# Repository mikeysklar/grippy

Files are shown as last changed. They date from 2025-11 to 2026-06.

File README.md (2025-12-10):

# Grippy – Ultracompact One-Handed Keyboard

## Overview

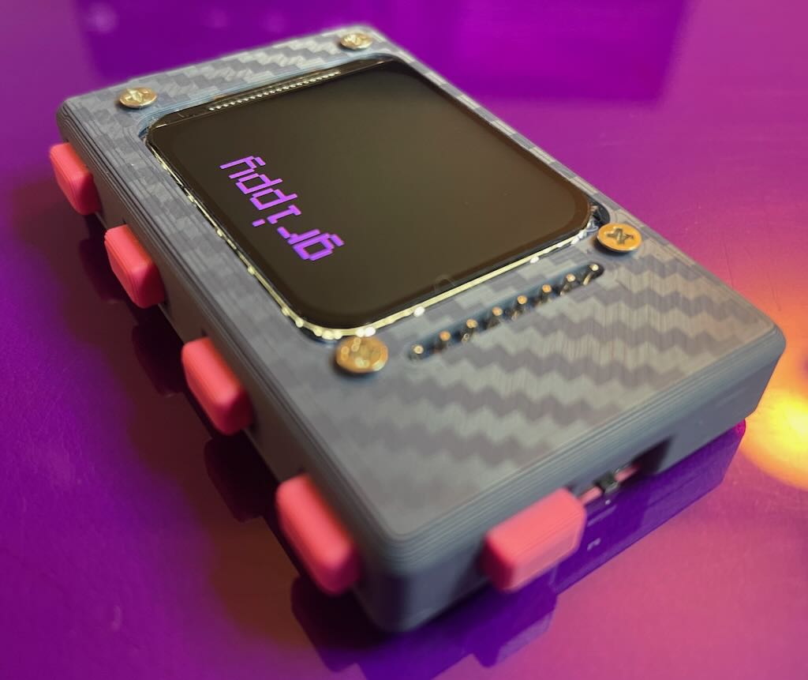
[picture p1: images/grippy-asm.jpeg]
Grippy Assembled


Originally designed as a one-handed chording keyboard for wearables, Grippy has grown through five iterations into a slim, ultralight everyday-carry note-taking device.

Typing around 30 WPM with a single hand—and even inside your pocket—is completely realistic.

Grippy also doubles as a USB or BLE keyboard for phones, tablets, and computers.

---

## Features

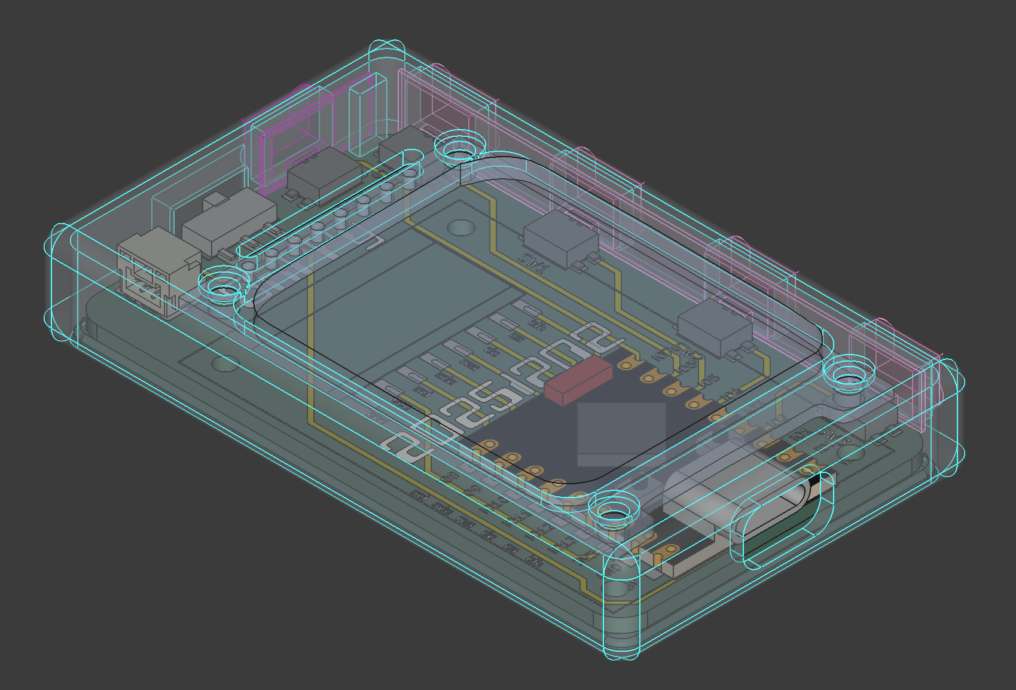
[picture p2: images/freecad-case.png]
FreeCAD


- **Slim & Lightweight**
  - About the thickness of a AAA battery  
  - ~7× lighter than an iPhone  

- **One-Handed SAIE Chording**
  - Full text entry: letters, numbers, symbols  
  - Three layers, zero finger travel  

- **EDC Note-Taking**
  - Write and review notes directly on the device  
  - Works even while pocketed  

- **USB Keyboard Mode**
  - USB HID for quick input or macros  

- **BLE Keyboard Mode**
  - Wireless typing to phones and computers  

- **USB Storage Mode**
  - Mounts as a flash drive to edit notes  

- **Open & Hackable**
  - KiCad, STEP, FreeCAD, and 3MF files  
  - CircuitPython 10.x firmware + chording config

---

## Specs

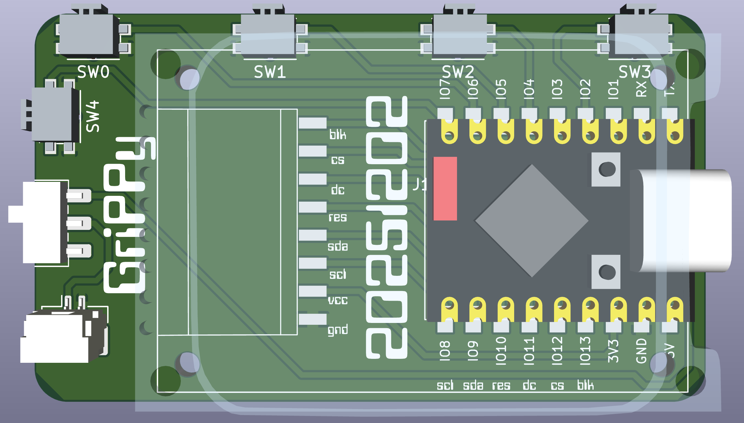
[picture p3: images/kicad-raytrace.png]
3D Board


| Item | Value |
| --- | --- |
| Dimensions  | 61 x 35 x 11 mm |
| Weight | 29 grams |
| Firmware | CircuitPython 10.x |
| Controller  | ESP32-S3 |
| Construction| SMD components on PCB  |

---

## PCB

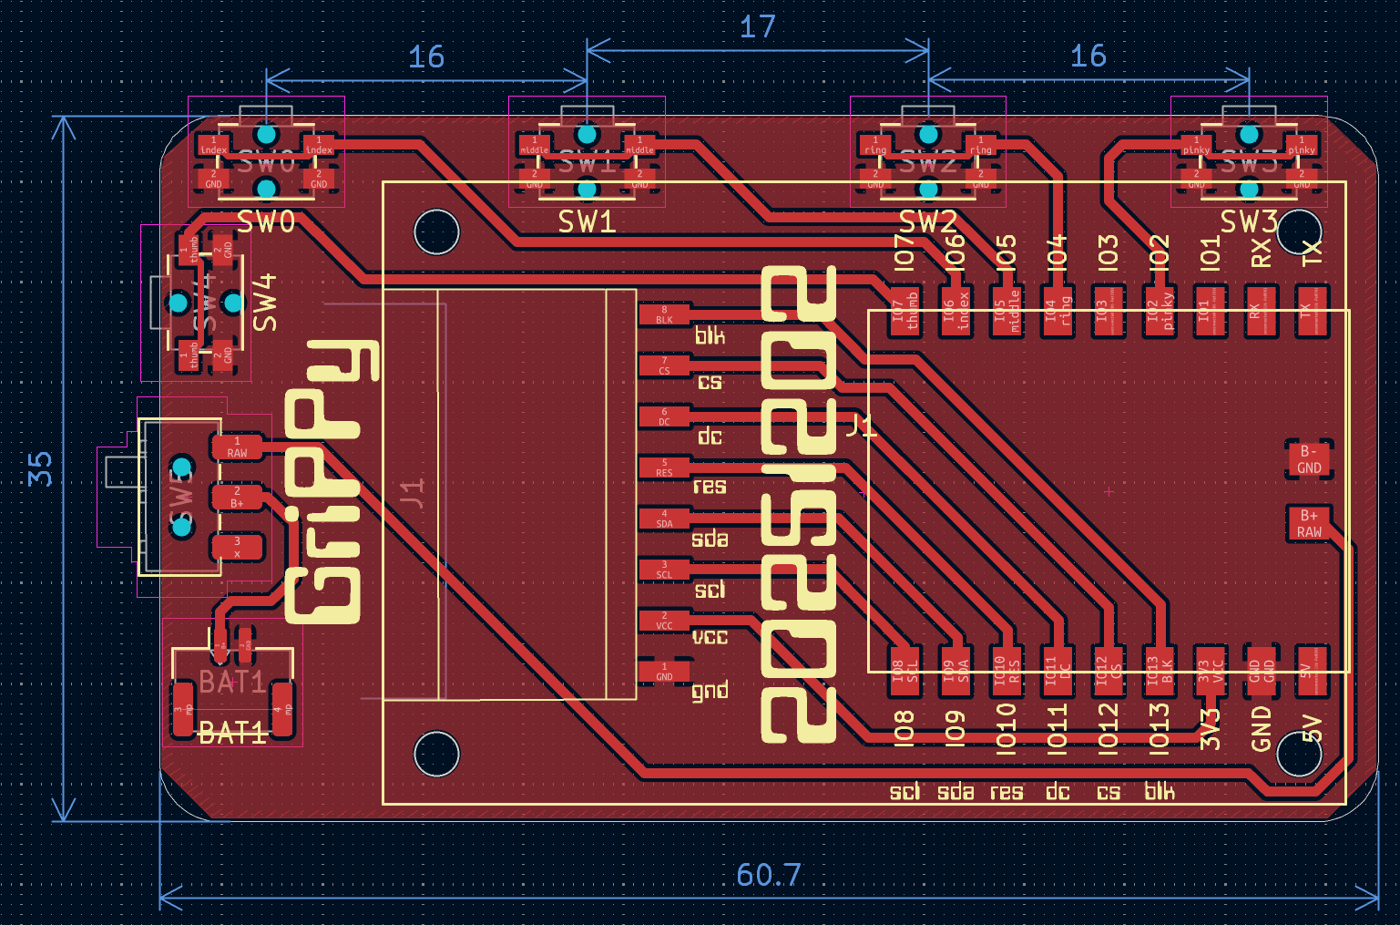
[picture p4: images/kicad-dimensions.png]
PCB Dimensions


- KiCAD 9.x
- single sided PCB
- SMT design

---

## Stencil

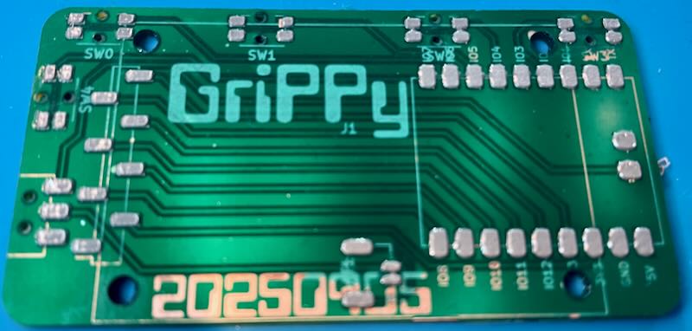
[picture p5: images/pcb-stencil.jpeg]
PCB Stencil


- low temp 140C solderpaste
- laser cut metal business card

---

## Schematic

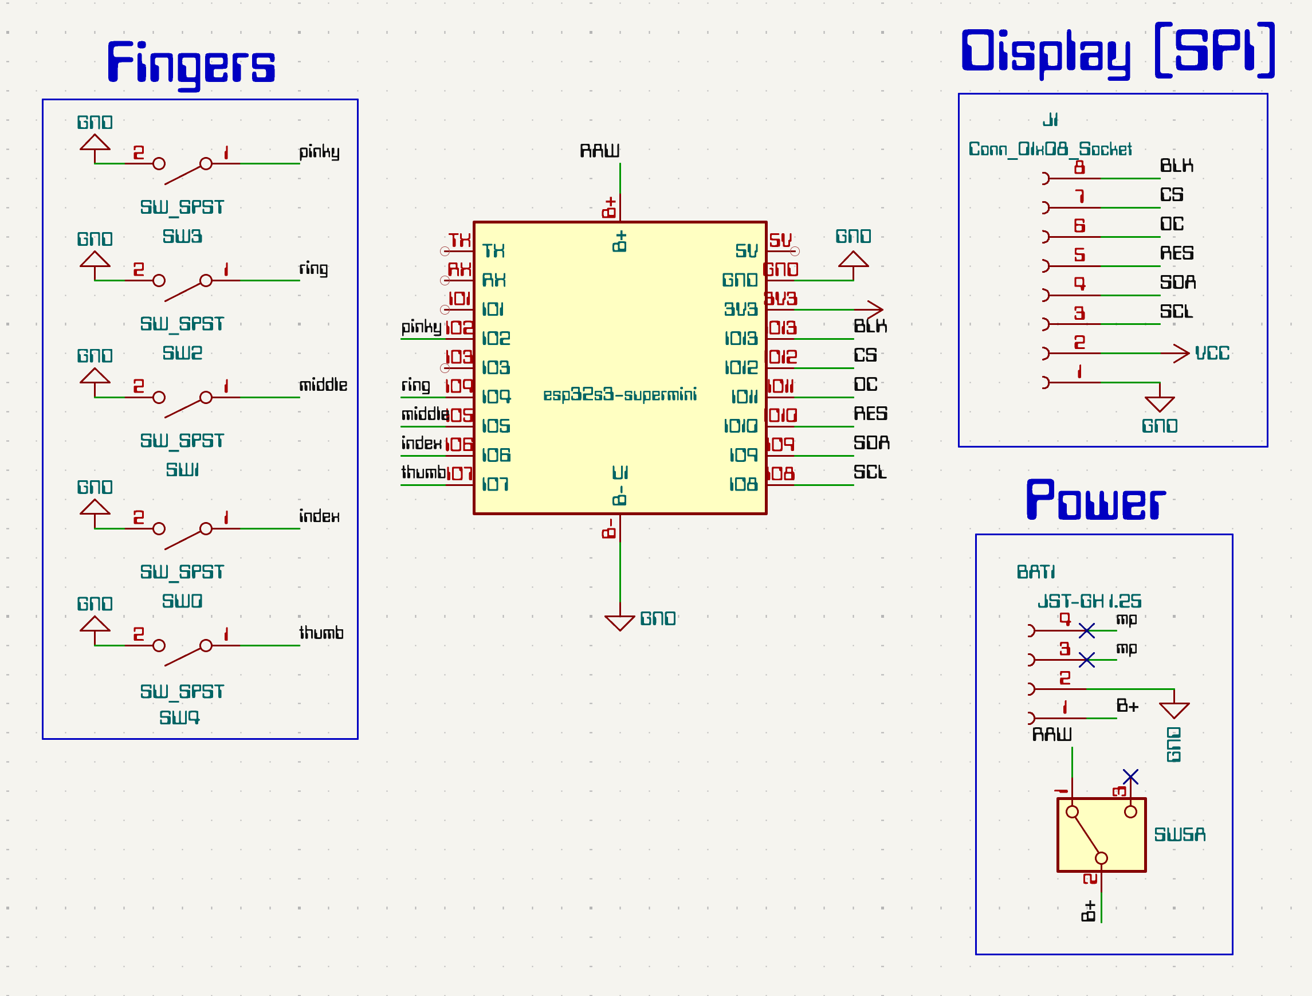
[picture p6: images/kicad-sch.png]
PCB schematic


---

## CircuitPython Setup

- <a href="https://circuitpython.org/board/espressif_esp32s3_devkitc_1_n8/">Bootloader 0.35.0 or later</a>
- <a href="https://circuitpython.org/board/espressif_esp32s3_devkitc_1_n8/">CircuitPython 10.0.3 or later</a>

install library dependencies:

```
circup install adafruit_st7789 adafruit_display_text adafruit_hid
```

copy code:

```
cp src/* CIRCUITPY/
```

---

## BOM

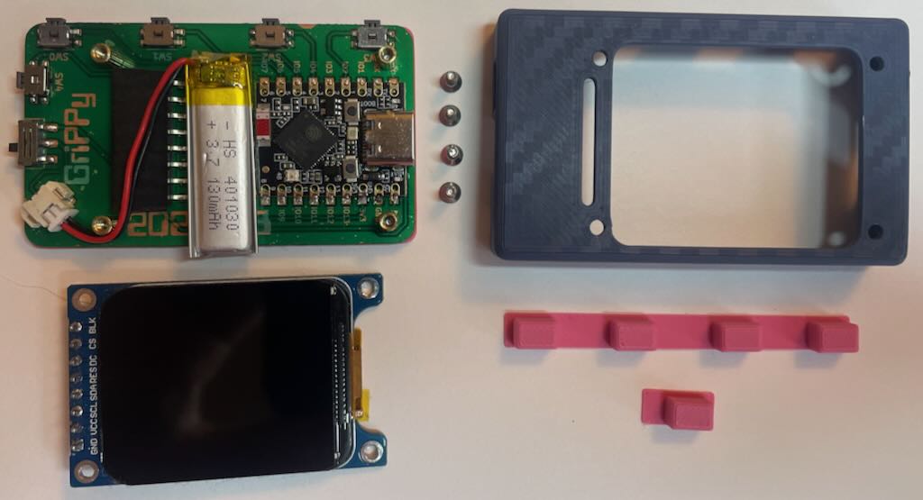
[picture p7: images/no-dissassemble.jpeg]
Inside


| Part | Desc. | Qty |
| --- | --- | --- |
| <a href="https://amzn.to/4idmH0o">ESP32-S3 SuperMini</a> | dual-core 240MHz / 512KB SRAM / 4MB Flash | 1 |
| <a href="https://amzn.to/484M9jT">1.69” TFT Display</a> | ST7789 SPI | 1 |
| <a href="https://www.digikey.com/en/products/detail/panasonic-electronic-components/EVQ-PUL02K/286340">Panasonic Tactile Switch</a> | EVQ-PUL02K SPST-NO Side Actuated | 1 |
| <a href=https://amzn.to/48axBAR>Standoff</a> | M2 × 5 mm | 4 |
| <a href=https://amzn.to/44vQJXr>Screws</a>| M2 × 5 mm | 8 |
| <a href=https://www.aliexpress.us/item/3256804992051151.html>Female SMD Header</a> | 8-pin | 1 |
| <a href=https://www.aliexpress.us/item/3256807383526945.html>Rt Ang Male Header | 8-pin | 1 |
| <a href=https://www.ebay.com/itm/357161444108>Small LiPo Battery | 130 mAh (JST-1.25) | 1 |
| <a href="https://www.aliexpress.us/item/3256805695475806.html">Slide Switch</a>| MSTK-12c03 | 1 |

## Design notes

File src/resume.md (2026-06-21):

# grippy — session resume

Handoff notes to continue this work from another machine.

## Device
- **Board:** ESP32-S3-DevKitC-1-**N8** (8 MB flash, **no PSRAM**, 512 KB SRAM).
- **CircuitPython:** 10.2.0.
- **Display:** 1.69" ST7789 IPS 240×280 (driven 280×240 rot 270) over SPI; **backlight on IO13** (on/off only — PWM has no effect on this panel).
- **Switches:** `SW_PINS = (IO6, IO5, IO4, IO2, IO7)` → chord indices 0–4; **index 4 = thumb** (taps select layers 1–7).
- **Battery:** 130 mAh LiPo. Key constraint — it **cannot source WiFi's sustained ~200–340 mA association burst** → brownout reboot loop. This drove the whole design.

## Git state
- Branch: **`backlight-off`** (off `main`; `main` untouched).
- Committed: `a8b5f0b` "working backlight off" (the original `(3,4)` backlight toggle).
- **Uncommitted/working changes since then** (boot-dark, wake-on-keypress, and now BLE) — see "What changed this session."
- `settings.toml` is **device-local, not in the repo** (never committed — safe for creds).
- ⚠️ If picking up on a different machine, **push from the original machine and pull here**, or these working-tree changes won't be present.

## Power profile (measured, @ ~5.16 V)
| State | WiFi | Backlight | Draw |
|---|---|---|---|
| idle, screen on | idle | on | 150 mA |
| idle, screen off | idle | off | 70 mA |
| screen on, no wifi | off | on | 140 mA |
| both off | off | off | ~60 mA |
| active web access, screen off | TX | off | 130–170 mA |

Decomposition: **base ~60 mA, backlight ~80 mA, WiFi idle ~10 mA, WiFi TX spikes ~200 mA+** (the brownout cause).

## Design decisions (settled)
1. **WiFi is dead on battery.** Any `CIRCUITPY_WIFI_SSID` in `settings.toml` → boot brownout loop (display blinks). Confirmed empirically. Do **not** put WiFi creds in settings.toml.
2. **Backlight boots dark; any key wakes it.** Saves ~80 mA. Reuses the sleep/wake logic.
3. **Never radio + display both on** (battery budget). `(3,4)` = Remote (display off), wake = Local (display on).
4. **Pivoted to BLE** for wireless `notes.txt` editing — low duty cycle, no sustained spike, and `supervisor.runtime.ble_workflow` is a **runtime toggle** (no reload, no settings.toml hacks).

## What changed this session (in `src/code.py`)
- **Boot dark:** both backlight init lines set `bl.value = False` (was a bug — a second line at the old ~line 72 was relighting it).
- **Sleep/wake:** `(3,4)` on layer 3 = sleep (backlight off); **any key on any layer wakes** (rising-edge gated so the `(3,4)` release flicker doesn't re-wake; wake press is consumed). Lives in `check_chords()` as an early `if not bl.value:` block.
- **BLE (new):** at boot, WiFi radio off + `supervisor.runtime.ble_workflow = False` (low power). `(3,4)` → backlight off + `ble_workflow = True`. Wake → backlight on + `ble_workflow = False`.
- Removed all the dead WiFi-connect code (`os`/`wifi` top imports, `ON_BATTERY`, runtime connect).

## settings.toml (device-local) — set this on the board
```toml
CIRCUITPY_BLE_NAME = "grippy"
# NO CIRCUITPY_WIFI_* keys (they brown out the battery at boot)
```

## NEXT STEP — test BLE (do this first)
1. Deploy `src/code.py` to the board (USB drive `cp` when CIRCUITPY mounts host-writable, or Web Workflow — but WW needs WiFi which we removed, so use the **USB drive**). Set `CIRCUITPY_BLE_NAME = "grippy"` in `settings.toml`.
2. On the device: tap thumb ×3 → layer 3, press **thumb+pinky `(3,4)`** → screen goes dark, BLE workflow turns on (serial prints `Remote: backlight OFF, BLE workflow ON (grippy)`).
3. **From a Mac (guaranteed path):** open **Chrome** → `https://code.circuitpython.org` → "Connect via BLE" → pick `grippy` → open/edit/save `notes.txt`.
4. **From iPhone/iPad (untested):** Safari has no Web Bluetooth. Try the **Bluefy** app pointed at `code.circuitpython.org`. If it fails, fall back to a custom Nordic-UART service + Bluefruit Connect (see research below).
5. Test **on battery** to confirm BLE doesn't brown out the 130 mAh cell. (Editing `notes.txt` over BLE only works when CircuitPython owns the FS, i.e. on battery / no USB host; read-only when plugged into USB.)

## Known gotchas / risks
- **No bulk cap (no space).** BLE peaks are still brief ~170 mA — *probably* fine (sub-ms blips vs WiFi's sustained burst) but unverified on this cell. Main thing to confirm in testing.
- **RAM:** no PSRAM. Watch `gc.mem_free()` with BLE + displayio + HID; most likely failure mode.
- **BLE bonding bug** (adafruit/circuitpython #9708) on ESP32-S3 — repeated pair/bond cycles can hard-fault to safe mode; avoid bonding / `_bleio.adapter.erase_bonding()` if it acts up. May still affect 10.2.0.
- **Random EDIT/NOTES storage mode at boot** (no boot.py → `usb_connected` unreliable early). Makes USB deploys flaky — retry resets until CIRCUITPY mounts host-writable, or add a deterministic `boot.py` (wait-for-enumeration → remount). Not yet done.
- Backlight boot **flash**: IO13 floats high (backlight on) from power-on until `code.py` drives it low — unavoidable in software (would need an IO13 pulldown resistor).

## Open / possible follow-ups
- Decide iOS path (Bluefy vs custom NUS service) after testing.
- Optional deterministic `boot.py` to stop the EDIT/NOTES flapping.
- The bigger **Settings menu** idea (layer renumber inserting a Menu at layer 3, combined items) was deferred in favor of this power/BLE work.
- Commit the BLE work and merge `backlight-off` → `main` once BLE is verified.

## Tooling notes
- Board reachable over USB serial via the `circuitpython-repl` MCP (`/dev/cu.usbmodem0FE9E9A75CC81`). The MCP REPL **resets its namespace between calls** — put multi-step snippets in one call.
- Web Workflow creds were `circuitpython.local` / device host `cpy-3_devkitc_1_n8-f09e9e7ac58c.local`, API password `funafuti` — but WiFi is now removed, so Web Workflow is gone; deploy via USB drive.

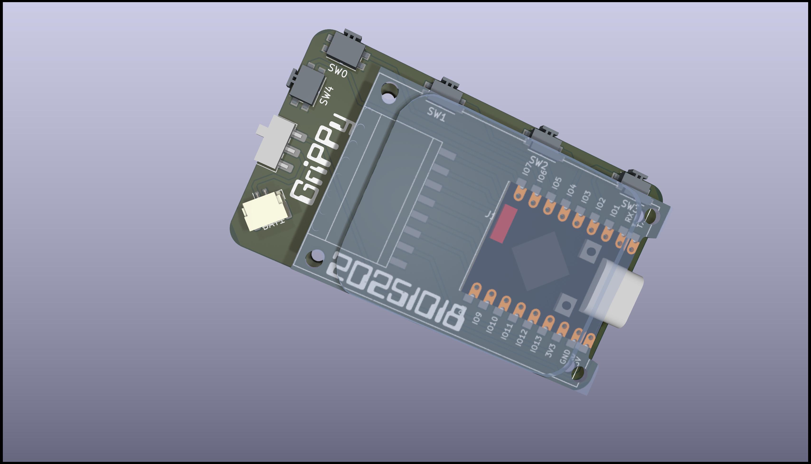
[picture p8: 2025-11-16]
images/kicad-raytrace.jpg

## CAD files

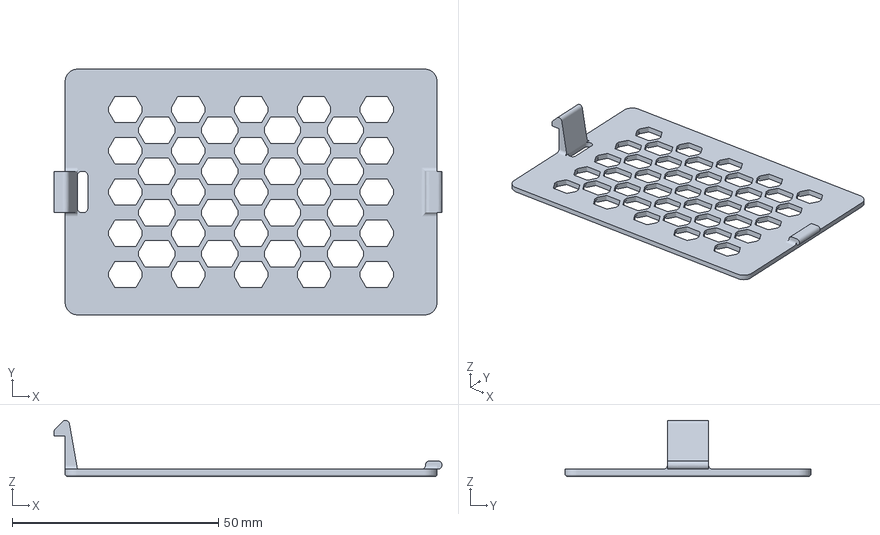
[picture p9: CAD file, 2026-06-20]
cad/grippy-cap.3mf
94.1 x 59.6 x 13.7 mm

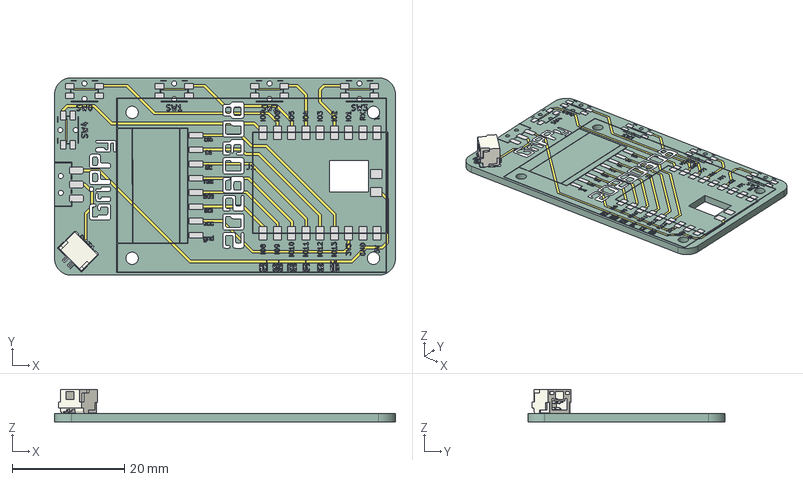
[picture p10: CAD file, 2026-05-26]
grippy/grippy.step
60.8 x 35.2 x 5.92 mm
JST_GH_SM02B-GHS-TB_1x02-1MP_P1.25mm_Horizontal
grippy_copper
grippy_pad
grippy_silkscreen
grippy_PCB

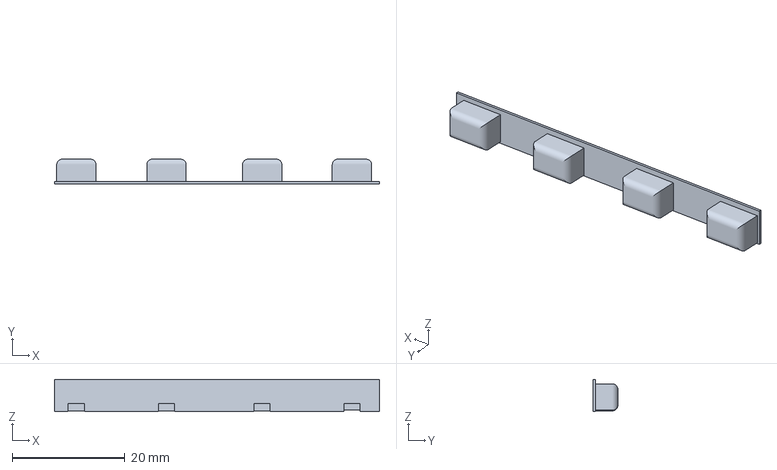
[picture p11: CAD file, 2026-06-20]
cad/grippy-button_fingers.3mf
57.8 x 4.40 x 5.75 mm

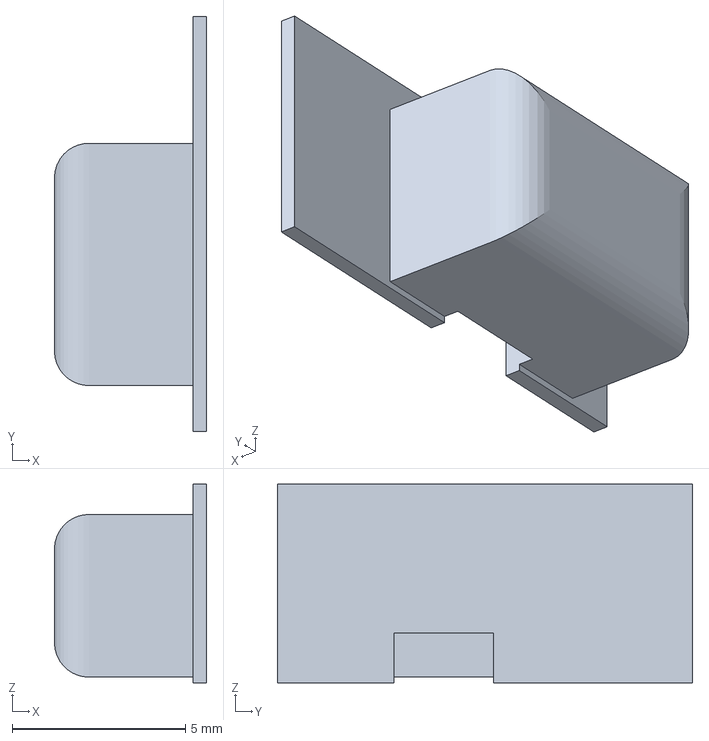
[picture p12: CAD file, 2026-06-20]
cad/grippy-button_thumb.3mf
4.40 x 12.0 x 5.75 mm

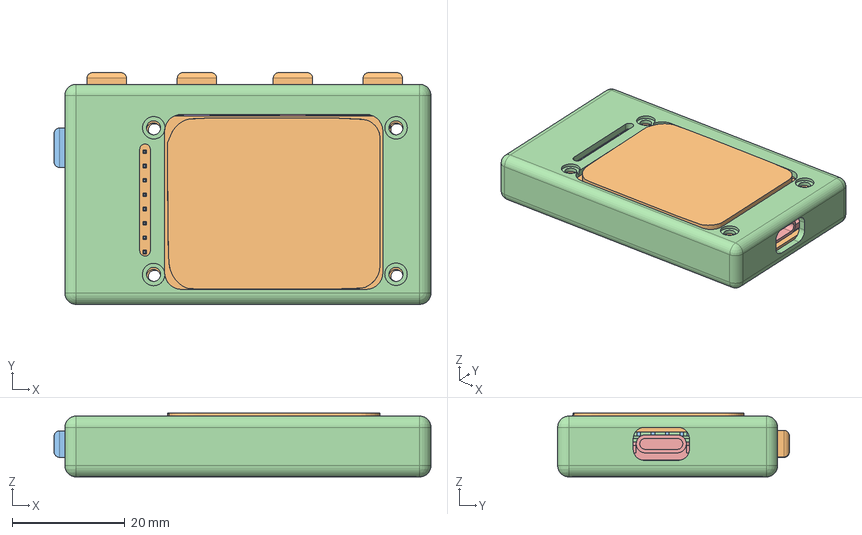
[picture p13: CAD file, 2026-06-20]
cad/grippy.FCStd
66.9 x 41.1 x 11.3 mm
ESP32S3 Super Mini
JST_GH_SM02B-GHS-TB_1x02-1MP_P1.25mm_Horizontal
PinHeader_1x08_P254mm_Horizontal
PinSocket_1x08_P2.54mm_Vertical
grippy_copper
grippy_copper001
grippy_copper002
grippy_copper003
grippy_copper004
grippy_copper005
grippy_copper006
grippy_copper007
grippy_copper008
grippy_copper009
grippy_copper010
grippy_copper011
grippy_copper012
grippy_copper013
grippy_copper014
grippy_pad
grippy_pad001
grippy_pad002
grippy_pad003
grippy_pad004
grippy_pad005
grippy_pad006
grippy_pad007
grippy_pad008
grippy_pad009
grippy_pad010
grippy_pad011
grippy_pad012
grippy_pad013
grippy_pad014
grippy_pad015
grippy_pad016
grippy_pad017
grippy_pad018
grippy_pad019
grippy_pad020
grippy_pad021
grippy_pad022
grippy_pad023
grippy_pad024
grippy_pad025
grippy_pad026
grippy_pad027
grippy_pad028
grippy_pad029
grippy_pad030
grippy_pad031
grippy_pad032
grippy_pad033
grippy_pad034
grippy_pad035
grippy_pad036
grippy_pad037
grippy_pad038
grippy_pad039
grippy_pad040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

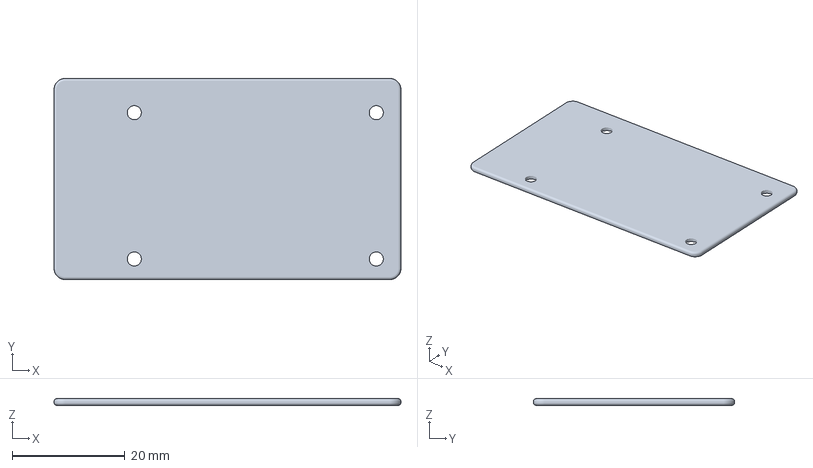
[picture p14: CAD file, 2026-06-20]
cad/grippy-base.3mf
61.7 x 35.8 x 1.20 mm

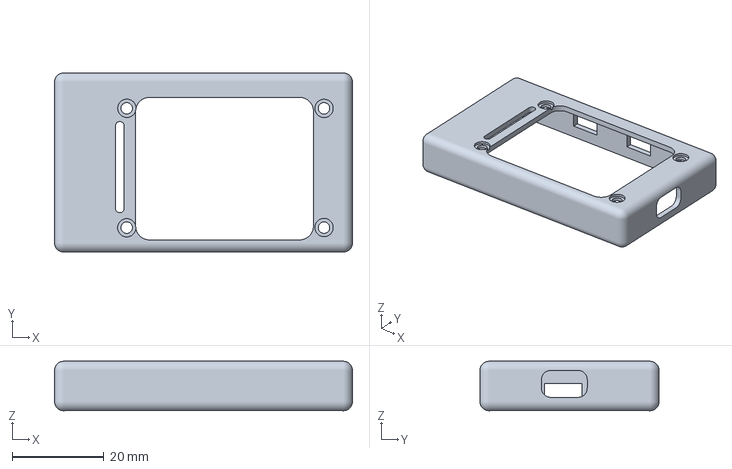
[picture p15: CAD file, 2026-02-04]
cad/grippy-capPocket049.3mf
65.0 x 39.0 x 10.8 mm

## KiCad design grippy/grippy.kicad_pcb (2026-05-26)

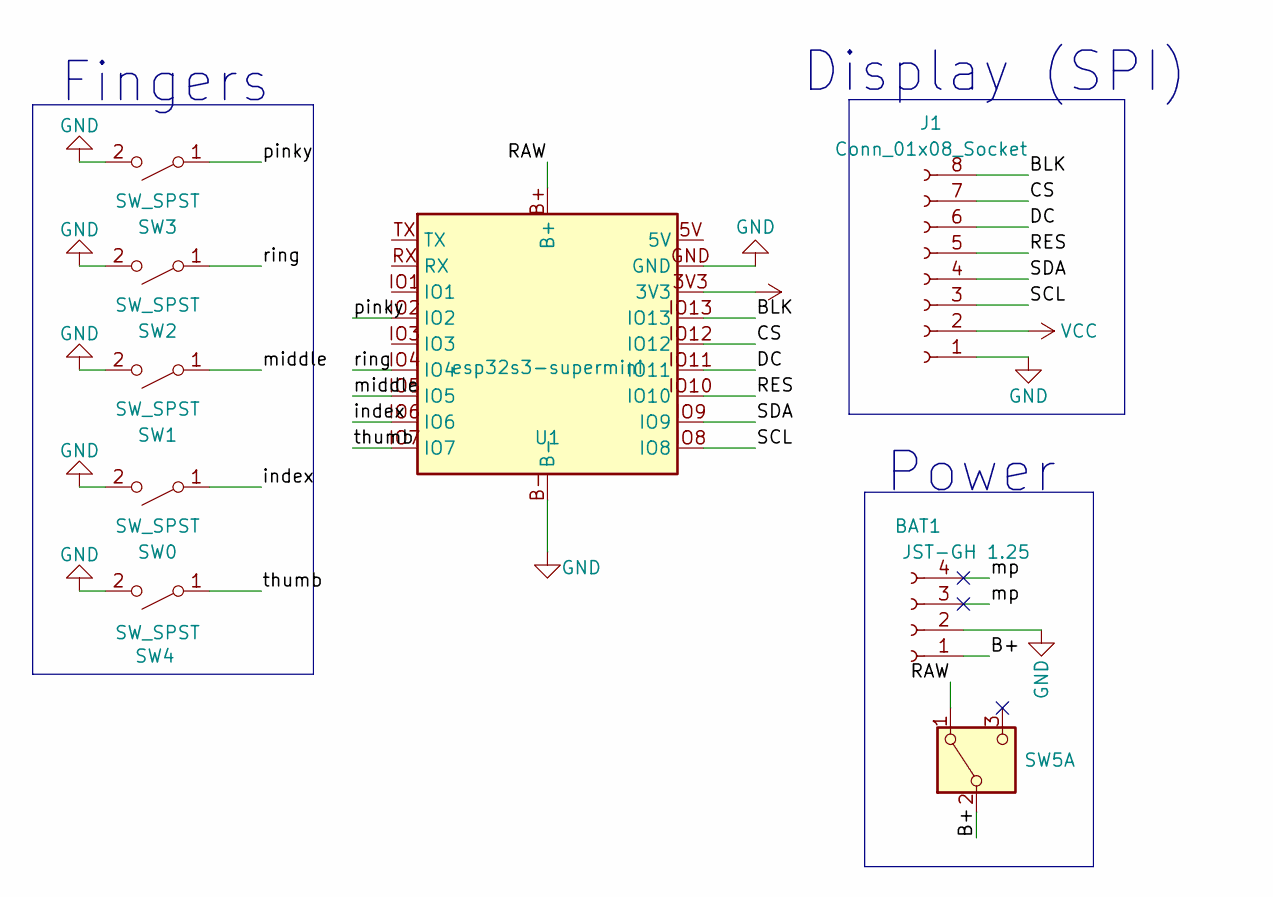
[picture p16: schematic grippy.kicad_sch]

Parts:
BAT1: JST-GH 1.25; JST_GH_SM02B-GHS-TB_1x02-1MP_P1.25mm_Horizontal
J1: Conn_01x08_Socket; tft-169-st7789-rt-ang
SW0, SW1, SW2, SW3, SW4: SW_SPST; Panasonic_EVQPUL_EVQPUC
SW5: SW_DPDT_x2; Untitled
U1: esp32s3-supermini; ESP32-S3-SuperMini_SMT

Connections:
/B+: BAT1.1, SW5.2 (B)
/BLK: J1.8, U1.IO13
/CS: J1.7, U1.IO12
/DC: J1.6, U1.IO11
/RAW: SW5.1 (A), U1.B+
/RES: J1.5, U1.IO10
/SCL: J1.3, U1.IO8
/SDA: J1.4, U1.IO9
/index: SW0.1 (A), U1.IO6
/middle: SW1.1 (A), U1.IO5
/mp: BAT1.3, BAT1.4
/pinky: SW3.1 (A), U1.IO2
/ring: SW2.1 (A), U1.IO4
/thumb: SW4.1 (A), U1.IO7
GND: BAT1.2, J1.1, SW0.2 (B), SW1.2 (B), SW2.2 (B), SW3.2 (B), SW4.2 (B), U1.B-, U1.GND
VCC: J1.2, U1.3V3

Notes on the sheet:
Fingers
Display (SPI)
Power

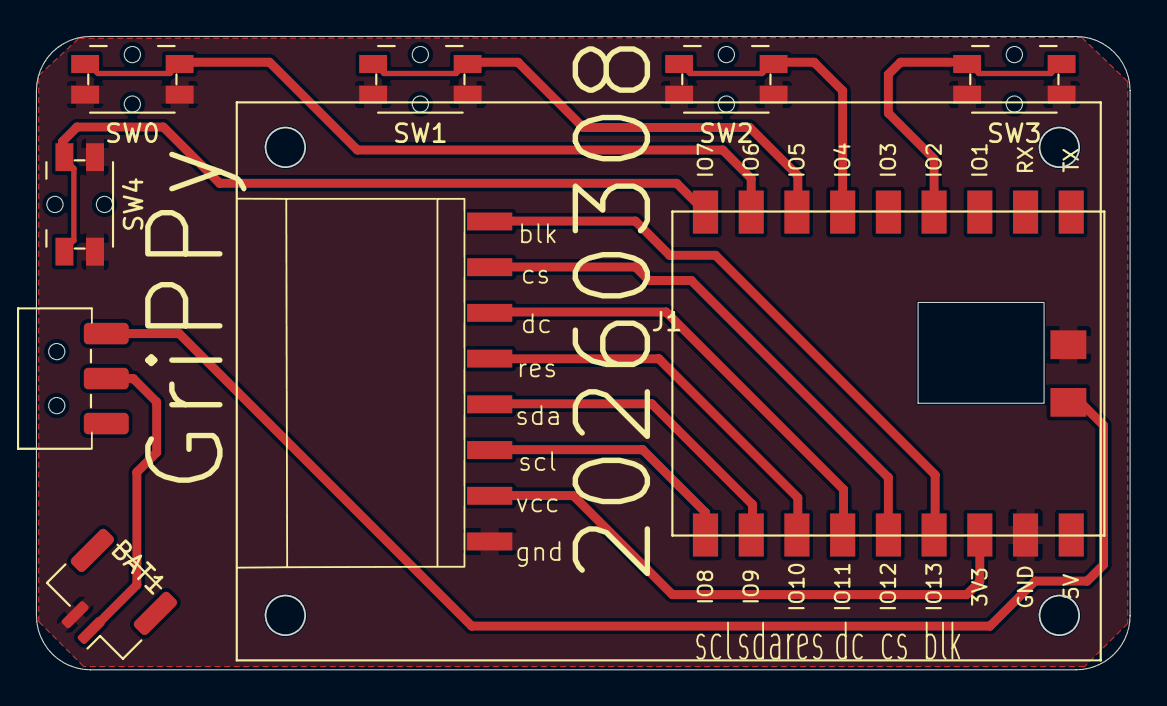
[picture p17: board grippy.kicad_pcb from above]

Board: 2 copper layers, 60.8 x 35.2 mm, 9 parts (0 on the bottom side), 16 nets.

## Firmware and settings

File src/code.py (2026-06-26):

import time
import digitalio
import board
import busio
import displayio
from fourwire import FourWire
from adafruit_st7789 import ST7789
import terminalio
from adafruit_display_text import bitmap_label as label
import chords_config
import webserver
import notes
import game
import ble_hid

time.sleep(0.25)
displayio.release_displays()

# --- WiFi radio off (no networking; saves power) ---
try:
    import wifi
    wifi.radio.enabled = False
except Exception:
    pass

# --- BLE radio: OFF at boot (enabled on demand) ---
# An enabled-but-idle BLE controller draws current on EVERY boot even when BLE
# is never used. So leave the adapter OFF here and let ble_hid.start() power it
# up the first time the BLE menu item is selected (with a settle delay before
# advertising, so we still don't toggle adapter.enabled right next to a
# start_advertising — the thing that used to corrupt the controller).
#
# Still disable CircuitPython's built-in BLE WORKFLOW. It auto-advertises as
# CIRCUITPYxxxx and re-advertises on every disconnect, fighting ble_hid for the
# single radio — that caused the stray "CIRCUITPYac58e" name, macOS staying
# connected after BLE-off (workflow re-advertised → host reconnected), and the
# flaky pairing. boot.py disables it before it ever starts on a hard reset; this
# line covers soft resets (Ctrl-D), where boot.py does not run.
try:
    import supervisor
    supervisor.runtime.ble_workflow = False
except Exception:
    pass
try:
    import _bleio
    if _bleio.adapter.advertising:
        _bleio.adapter.stop_advertising()
    _bleio.adapter.enabled = False
except Exception:
    pass

# --- Backlight ---
bl = digitalio.DigitalInOut(board.IO13)
bl.direction = digitalio.Direction.OUTPUT
bl.value = True

# --- Onboard RGB LED off (case covers it; saves power) ---
# CircuitPython drives the WS2812 on board.NEOPIXEL as a status LED. Drive it to
# black with the built-in neopixel_write (no neopixel lib needed) and release the
# pin. (The separate red power LED is hardwired to 3V3 — not software-controllable.)
try:
    import neopixel_write
    _np = digitalio.DigitalInOut(board.NEOPIXEL)
    _np.direction = digitalio.Direction.OUTPUT
    neopixel_write.neopixel_write(_np, bytearray([0, 0, 0]))
    _np.deinit()
except Exception:
    pass

# --- SPI + 4-wire display bus ---
spi = busio.SPI(clock=board.IO8, MOSI=board.IO9)   # no MISO required
display_bus = FourWire(
    spi,
    command=board.IO11,        # D/C
    chip_select=board.IO12,    # CS
    reset=board.IO10,          # RST
    baudrate=60_000_000
)

# --- ST7789 panel (280x240 variant) ---
display = ST7789(
    display_bus,
    width=280,
    height=240,
    rotation=270,
    rowstart=20,
    colstart=0,
    auto_refresh=False,
)

display_group = displayio.Group(scale=1)
display.root_group = display_group

# --- Black background tile ---
bg_bitmap = displayio.Bitmap(280, 240, 1)
bg_palette = displayio.Palette(1)
bg_palette[0] = 0x000000
bg = displayio.TileGrid(bg_bitmap, pixel_shader=bg_palette)
display_group.append(bg)

try:
    display.refresh(minimum_frames_per_second=0)
except TypeError:
    display.refresh()

bl.value = True  # backlight on

# ─── Text buffer ─────────────────────────────────────────────────────
text_buffer = ""

# ─── Switch inputs ───────────────────────────────────────────────────
SW_PINS = (board.IO6, board.IO5, board.IO4, board.IO2, board.IO7)
pins = []
for gp in SW_PINS:
    p = digitalio.DigitalInOut(gp)
    p.direction = digitalio.Direction.INPUT
    p.pull = digitalio.Pull.UP
    pins.append(p)

# ─── Keyboard output (start OFF) ─────────────────────────────────────
# Two transports, one at a time: USB HID (`usbmode`, local `keyboard`) and
# BLE HID (`blemode`, owned by ble_hid). _kbd() returns whichever is ready to
# send (None if off, or BLE-on-but-not-yet-connected).
usbmode = False
blemode = False
keyboard = None
ble_err  = ""        # last BLE-enable error (shown on screen for debugging)

def enable_hid():
    global usbmode, keyboard
    if blemode:
        disable_ble()            # one transport at a time
    import usb_hid
    from adafruit_hid.keyboard import Keyboard
    keyboard = Keyboard(usb_hid.devices)
    usbmode = True
    print("USB HID enabled")

def disable_hid():
    global usbmode, keyboard
    keyboard = None
    usbmode = False
    print("USB HID disabled")

def enable_ble():
    global blemode, ble_err
    if usbmode:
        disable_hid()            # one transport at a time
    import gc
    gc.collect()
    print("BLE: free heap before start =", gc.mem_free())
    try:
        ble_hid.start("grippy")
        blemode = True
        ble_err = ""
        print("BLE HID enabled (advertising as grippy)")
    except Exception as e:
        blemode = False          # never crash the device on a radio hiccup
        ble_err = repr(e)
        try:
            ble_hid.stop()
        except Exception:
            pass
        print("BLE enable FAILED:", ble_err)

def disable_ble():
    global blemode
    ble_hid.stop()
    blemode = False
    print("BLE HID disabled")

def _kbd():
    """The keyboard ready to send right now, or None."""
    if usbmode:
        return keyboard
    if blemode:
        return ble_hid.kbd()     # None until a host connects
    return None

# ─── Timing constants ────────────────────────────────────────────────
SCAN_LOOP = 0.001
# While the screen is OFF (local sleep or WiFi Sync) there is nothing to type,
# so we don't need the 1 ms chord-scan cadence — spinning that fast keeps the
# ESP32-S3 CPU out of idle and burns ~70 mA extra (measured: screen-off+WiFi
# busy-spin 140 mA vs 70 mA when the CPU is allowed to idle). Poll at 20 Hz
# instead: still wakes on a keypress / serves HTTP within 50 ms, but lets the
# CPU idle so screen-off draw drops back to ~70 mA on the 130 mAh cell.
SLEEP_LOOP = 0.05
STABLE_MS_ALPHA = 0.03
STABLE_MS_OTHER = 0.02
DEBOUNCE_UP      = 0.05
TAP_WINDOW       = 0.5
MIN_TAP_INT      = 0.1
L5_REPEAT_MS     = 0.1
NAV_REPEAT_MS    = 0.2
LAYER_LOCK_COOLDOWN = 0.1
SCROLL_REPEAT_MS  = 0.15
THUMB_HOLD_TO_LOCK = 0.12
LONG_HOLD_MENU    = 0.70   # thumb-only hold ≥ this ⇒ jump to the menu (longer = taps to alpha are safer)
NEXT_OK = 0.0

# ─── State variables ────────────────────────────────────────────────
layer            = 1
thumb_taps       = 0
tap_in_prog      = False
thumb_down_at    = 0.0
long_hold_fired  = False
thumb_gesture    = False   # True only while the thumb is held ALONE from rest;
                           # a lone (4,) reached by releasing a chord's fingers
                           # is NOT a gesture (it's a chord tail) and must reach
                           # the typing/game handler instead of switching layer.
last_tap_time    = 0.0
last_combo       = ()
pending_combo    = None
sent_release     = False
skip_scag        = False
scag_skip_combo  = None
modifier_armed   = False
held_modifier    = None
last_time        = time.monotonic()
held_combo       = ()
last_repeat      = 0.0
accel_active     = False
held_nav_combo   = ()
last_nav         = 0.0
last_pending_combo = None
last_layer_change = 0.0
held_scroll_combo = ()
last_scroll       = 0.0
last_thumb_rise    = 0.0
thumb_locked       = False
viewer_mode  = False
entries      = []
entry_idx    = 0
entry_offset = 0
typing_offset = 0

# ─── Menu / sub-mode state ───────────────────────────────────────────
# A note auto-saves on the long-hold back to the menu (the only way home),
# so layer switches never commit and there's no separate Save item.
_BASE_MENU = ["New Note", "View Note", "WiFi Sync", "Clr Note", "Game Mode", "BLE", "Clr BLE", "HID", "Clr All"]
menu_idx          = 0
menu_top          = 0
confirm_clear_all = False
confirm_clr_ble   = False     # "Clr BLE" two-tap confirm (erases BLE bonds)
clear_mode        = False     # "Clr Note" picker active
clear_idx         = 0
clear_top         = 0
game_mode         = False     # chord-trainer (game.py) active

# ─── Text window geometry for ST7789 ─────────────────────────────────
SCALE   = 4
GLYPH_W = 6 * SCALE          # terminalio glyph is 6x8
GLYPH_H = 8 * SCALE
COLS    = 10                 # ~10 chars/row at scale=4 fits well
ROWS    = 5                  # 5 rows on screen
LEFT, TOP = 20, 0
LINE_SPACING = 11            # extra pixels between rows

line_labels = []
_shown_lines = [""] * ROWS
for r in range(ROWS):
    lbl = label.Label(
        terminalio.FONT,
        text="",
        color=0xFF00FF,
        x=LEFT,
        y=TOP + (r + 1) * GLYPH_H + r * LINE_SPACING,
        scale=SCALE,
    )
    display_group.append(lbl)
    line_labels.append(lbl)

def _set_line(row: int, s: str) -> bool:
    """Update one line if text changed; return True if dirtied."""
    if s != _shown_lines[row]:
        line_labels[row].text = s
        _shown_lines[row] = s
        return True
    return False

def _format_window_lines(s: str):
    win = COLS * ROWS
    s = s + " " * max(0, win - len(s))
    return [s[i:i+COLS] for i in range(0, win, COLS)]

def _wrap_lines(s: str, cols: int = COLS):
    """Word-wrap s into rows of <= cols chars, breaking on spaces so whole
    words drop to the next row instead of splitting (used by View mode).
    Honors explicit newlines; a word longer than cols is hard-split since it
    can never fit. Whitespace runs collapse to a single space."""
    out = []
    for para in s.split("\n"):
        words = para.split()
        if not words:
            out.append("")          # preserve blank lines / paragraph breaks
            continue
        line = ""
        for w in words:
            while len(w) > cols:    # too long to ever fit a row: hard-split
                if line:
                    out.append(line); line = ""
                out.append(w[:cols]); w = w[cols:]
            if not line:
                line = w
            elif len(line) + 1 + len(w) <= cols:
                line += " " + w
            else:
                out.append(line); line = w
        if line:
            out.append(line)
    return out

# ─── Budgeted manual refresh ─────────────────────────────────────────
USE_NS = hasattr(time, "monotonic_ns")
_now = (time.monotonic_ns if USE_NS else lambda: int(time.monotonic()*1_000_000_000))

NEEDS_REFRESH = False
LAST_REFRESH_NS = 0
MIN_REFRESH_INTERVAL_NS = int(1e9 / 55)   # ~55 fps cap (~18ms)

def _maybe_refresh_budgeted():
    global NEEDS_REFRESH, LAST_REFRESH_NS
    if not NEEDS_REFRESH:
        return
    now_ns = _now()
    if (now_ns - LAST_REFRESH_NS) >= MIN_REFRESH_INTERVAL_NS:
        try:
            display.refresh(minimum_frames_per_second=0)
        except TypeError:
            display.refresh()
        LAST_REFRESH_NS = now_ns
        NEEDS_REFRESH = False

# ─── edit view ──────────────────────────────────────────────
def render_typing_window():
    """Render a COLS×ROWS window of text_buffer starting at typing_offset."""
    global typing_offset, NEEDS_REFRESH
    win = COLS * ROWS
    typing_offset = max(0, min(typing_offset, max(0, len(text_buffer) - win)))
    start, end = typing_offset, typing_offset + win
    lines = _format_window_lines(text_buffer[start:end])
    dirty = False
    for r, s in enumerate(lines):
        dirty |= _set_line(r, s)
    if dirty:
        NEEDS_REFRESH = True

# ─── Save-to-file (note storage lives in notes.py) ───────────────────
def save_entry():
    global text_buffer
    if notes.append_entry(text_buffer.rstrip("\n")):
        text_buffer = ""
        render_typing_window()

# ─── viewer mode ───────────────────────────────────────────────
def load_entries():
    global entries, entry_idx, entry_offset
    entries = notes.read_entries()
    entry_idx = 0
    entry_offset = 0

def render_entry_window():
    global NEEDS_REFRESH
    if not entries:
        d = _set_line(0, "(no notes)")
        d |= _set_line(1, "")
        d |= _set_line(2, "")
        d |= _set_line(3, "")
        if d: NEEDS_REFRESH = True
        return
    s = entries[entry_idx]
    wrapped = _wrap_lines(s, COLS)          # break on spaces, no mid-word splits
    max_off = max(0, len(wrapped) - ROWS)
    start = max(0, min(entry_offset, max_off))
    view = wrapped[start:start+ROWS]
    d = False
    for r in range(ROWS):
        d |= _set_line(r, view[r] if r < len(view) else "")
    if d: NEEDS_REFRESH = True

def enter_viewer():
    # NOTE: do NOT clear text_buffer — an in-progress note must survive a peek
    # at the viewer (resume it later via "Add Note").
    global viewer_mode, NEEDS_REFRESH
    d = False
    for r in range(ROWS):
        d |= _set_line(r, "")
    if d: NEEDS_REFRESH = True
    load_entries()
    viewer_mode = True
    render_entry_window()

def _update_last_char_only():
    global NEEDS_REFRESH
    win = COLS * ROWS
    start = typing_offset
    caret = len(text_buffer) - 1
    if caret < start or caret >= start + win:
        return
    rel = caret - start
    row = rel // COLS
    row_start = start + row * COLS
    row_text = text_buffer[row_start:row_start+COLS]
    row_text = row_text + " " * max(0, COLS - len(row_text))
    if _set_line(row, row_text):
        NEEDS_REFRESH = True

# ─── Printable-char map for the local note buffer ────────────────────
# HID keycode → character to echo into text_buffer. Letters/digits are
# computed; punctuation & whitespace come from this table. Non-printable
# keys (Esc, arrows, nav, Delete) map to None → sent over HID but not echoed.
_KC_CHAR = {
    39: "0", 40: "\n", 43: " ", 44: " ", 45: "-", 46: "=",
    47: "[", 48: "]", 49: "\\", 51: ";", 52: "'", 53: "`",
    54: ",", 55: ".", 56: "/",
}

def _kc_to_char(kc):
    if 4 <= kc <= 29:
        return chr(kc - 4 + ord('a'))
    if 30 <= kc <= 38:
        return chr(kc - 30 + ord('1'))
    return _KC_CHAR.get(kc)

# ─── Menu (layer 1) ──────────────────────────────────────────────────
def menu_items():
    return _BASE_MENU

def render_menu():
    """Draw the layer-1 menu as a scrolling ROWS-high window with a > cursor."""
    global NEEDS_REFRESH, menu_top, menu_idx
    items = menu_items()
    n = len(items)
    if menu_idx >= n:
        menu_idx = n - 1
    if menu_idx < 0:
        menu_idx = 0
    if menu_idx < menu_top:
        menu_top = menu_idx
    elif menu_idx >= menu_top + ROWS:
        menu_top = menu_idx - ROWS + 1
    dirty = False
    for r in range(ROWS):
        i = menu_top + r
        if i < n:
            name = items[i]
            if name == "HID":
                name = "HID On" if usbmode else "HID Off"
            elif name == "BLE":
                # Off / advertising / connected, so you can see pairing succeed
                name = ("BLE " + ("Con" if ble_hid.connected() else "Adv")
                        ) if blemode else "BLE Off"
            elif name == "Clr All" and confirm_clear_all and i == menu_idx:
                name = "Clr All?!"
            elif name == "Clr BLE" and confirm_clr_ble and i == menu_idx:
                name = "Clr BLE?!"
            s = ((">" if i == menu_idx else " ") + name)[:COLS]
        else:
            s = ""
        dirty |= _set_line(r, s)
    if dirty:
        NEEDS_REFRESH = True

def clear_all_notes():
    if notes.write_entries([]):
        print("notes.txt emptied")

def menu_activate():
    """Run the highlighted menu item."""
    global layer, thumb_taps, viewer_mode, confirm_clear_all, confirm_clr_ble, usbmode, typing_offset
    item = menu_items()[menu_idx]
    if item != "Clr All":
        confirm_clear_all = False
    if item != "Clr BLE":
        confirm_clr_ble = False
    if item == "New Note":
        viewer_mode = False
        typing_offset = 0
        layer = 2
        thumb_taps = 1            # 1 tap == alpha
        render_typing_window()
    elif item == "View Note":
        enter_viewer()
    elif item == "Game Mode":
        enter_game()              # chord trainer
    elif item == "WiFi Sync":
        start_remote()            # screen off + WiFi up
    elif item == "Clr Note":
        enter_clear()             # per-note delete picker
    elif item == "Clr All":
        if not confirm_clear_all:
            confirm_clear_all = True
            render_menu()         # shows "Clr All?!" — select again to wipe
        else:
            confirm_clear_all = False
            clear_all_notes()
            render_menu()
    elif item == "Clr BLE":
        # Wipe stored BLE bonds so a host can pair fresh (recovers macOS "stuck
        # on pairing" from a stale on-device bond). Also Forget the device on the
        # host. Two-tap confirm so it isn't triggered by accident.
        if not confirm_clr_ble:
            confirm_clr_ble = True
            render_menu()         # shows "Clr BLE?!" — select again to erase
        else:
            confirm_clr_ble = False
            ok = ble_hid.erase_pairing()
            print("BLE bonds erased" if ok else "BLE erase failed")
            render_menu()
    elif item == "HID":
        if usbmode:
            disable_hid()
        else:
            enable_hid()
        render_menu()
    elif item == "BLE":
        if blemode:
            disable_ble()
            render_menu()
        else:
            enable_ble()
            if blemode:
                render_menu()
            else:
                # enable failed — surface the error on screen (serial dies when
                # the BLE adapter toggles, so this is the only way to read it)
                _draw_lines(["BLE FAIL"] +
                            [ble_err[i:i + COLS]
                             for i in range(0, min(len(ble_err), COLS * 4), COLS)])

def handle_menu_input(use):
    global menu_idx, confirm_clear_all, confirm_clr_ble
    n = len(menu_items())
    if use == (0,):
        menu_idx = (menu_idx - 1) % n
        confirm_clear_all = False
        confirm_clr_ble = False
        render_menu()
    elif use == (3,):
        menu_idx = (menu_idx + 1) % n
        confirm_clear_all = False
        confirm_clr_ble = False
        render_menu()
    elif use in ((1,), (2,), (1, 2)):
        menu_activate()

def handle_viewer_input(use):
    """0 = previous entry, 3 = next entry, select = back to menu."""
    global viewer_mode, entry_idx, entry_offset
    if use in ((1,), (2,), (1, 2)):
        viewer_mode = False
        render_menu()
        return
    if not entries:
        return
    if use == (0,):
        entry_idx = (entry_idx - 1) % len(entries)
        entry_offset = 0
        render_entry_window()
    elif use == (3,):
        entry_idx = (entry_idx + 1) % len(entries)
        entry_offset = 0
        render_entry_window()

# ─── Clr Note: per-entry delete picker ───────────────────────────────
def render_clear_list():
    """Scrolling list of notes.txt entries with a > cursor (for deletion)."""
    global NEEDS_REFRESH, clear_top
    n = len(entries)
    if n == 0:
        d = _set_line(0, "(no notes)")
        for r in range(1, ROWS):
            d |= _set_line(r, "")
        if d:
            NEEDS_REFRESH = True
        return
    if clear_idx < clear_top:
        clear_top = clear_idx
    elif clear_idx >= clear_top + ROWS:
        clear_top = clear_idx - ROWS + 1
    dirty = False
    for r in range(ROWS):
        i = clear_top + r
        if i < n:
            text = entries[i].replace("\n", " ")
            s = ((">" if i == clear_idx else " ") + text)[:COLS]
        else:
            s = ""
        dirty |= _set_line(r, s)
    if dirty:
        NEEDS_REFRESH = True

def enter_clear():
    global clear_mode, clear_idx, clear_top
    load_entries()
    clear_idx = 0
    clear_top = 0
    clear_mode = True
    render_clear_list()

def delete_entry(idx):
    """Rewrite notes.txt without entry idx (restores the list if write fails)."""
    if not (0 <= idx < len(entries)):
        return
    removed = entries[idx]
    del entries[idx]
    if notes.write_entries(entries):
        print("Deleted entry", idx)
    else:
        entries.insert(idx, removed)   # write failed (read-only) → undo

def handle_clear_input(use):
    global clear_mode, clear_idx
    if not entries:
        if use in ((0,), (3,), (1,), (2,), (1, 2)):
            clear_mode = False
            render_menu()
        return
    if use == (0,):
        clear_idx = (clear_idx - 1) % len(entries)
        render_clear_list()
    elif use == (3,):
        clear_idx = (clear_idx + 1) % len(entries)
        render_clear_list()
    elif use in ((1,), (2,), (1, 2)):
        delete_entry(clear_idx)
        if not entries:
            clear_mode = False
            render_menu()
        else:
            if clear_idx >= len(entries):
                clear_idx = len(entries) - 1
            render_clear_list()

# ─── Game (chord trainer) — logic in game.py ─────────────────────────
def _draw_lines(lines):
    """Blit a list of up to ROWS strings (game.py's display bridge)."""
    global NEEDS_REFRESH
    dirty = False
    for r in range(ROWS):
        s = lines[r] if r < len(lines) else ""
        dirty |= _set_line(r, s[:COLS])
    if dirty:
        NEEDS_REFRESH = True

def enter_game():
    global game_mode
    game_mode = True
    _draw_lines(game.start())

def handle_game_input(use):
    global game_mode
    r = game.handle(use)
    if r == "EXIT":
        game_mode = False
        render_menu()
    else:
        _draw_lines(r)

# ─── WiFi sync (remote) mode ─────────────────────────────────────────
# Boot stays WiFi-off (no boot connect → no association brownout). The
# "WiFi Sync" menu item turns the screen OFF and brings WiFi up only then,
# so the backlight (~80 mA) and the WiFi association spike never overlap.
# The networking lives in webserver.py; backlight ordering lives here.
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

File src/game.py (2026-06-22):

# game.py — chord-training game for grippy.
#
# A level-based trainer for learning the chord map one character at a time.
# Logic-only and display-free (like notes.py / webserver.py): every entry
# point returns a list of <=5 short strings for code.py to blit, or the
# sentinel "EXIT" to ask code.py to drop back to the main menu.
#
# Flow: the Game menu item lands on this module's own mode picker. Pick a
# mode → play. Long-hold (handled in code.py) always exits to the main menu.
#
# Modes (increasing difficulty):
#   Guided    — show the target AND its finger pattern; you copy it.
#   Hint Miss — recall from memory; a miss reveals the pattern, retry to clear.
#   Timed     — type simple words against a clock.

import time
import chords_config

# ─── target → chord lookup (built from the live chord maps) ──────────
def _kc_char(kc):
    if 4 <= kc <= 29:
        return chr(kc - 4 + ord('A'))   # A–Z (uppercase for display)
    if 30 <= kc <= 38:
        return chr(kc - 30 + ord('1'))  # 1–9
    if kc == 39:
        return '0'
    return None

_LETTER_CHORD = {}
for _chord, _kc in chords_config.alpha.items():
    _c = _kc_char(_kc)
    if _c and _c.isalpha():
        _LETTER_CHORD[_c] = _chord

_NUM_CHORD = {}
for _chord, _kc in chords_config.num_nav.items():
    _c = _kc_char(_kc)
    if _c and _c.isdigit():
        _NUM_CHORD[_c] = _chord

# space is its own chord (alpha (0,2,3)); derived so it tracks the live map
_SPACE_CHORD = None
for _chord, _kc in chords_config.alpha.items():
    if _kc == chords_config.Keycode.SPACE:
        _SPACE_CHORD = _chord
        break

def _chord_for(ch):
    if ch == ' ':
        return _SPACE_CHORD
    if ch.isdigit():
        return _NUM_CHORD.get(ch)
    return _LETTER_CHORD.get(ch.upper())

def _pattern(chord):
    """Render a chord as a 5-slot finger map: thumb + space + 4 fingers.
    Thumb is on the left to match the physical orientation of the thumb key.
    e.g. E=(0,) -> '- #---',  M=(0,4) -> '# #---'."""
    if not chord:
        return "?"
    fingers = "".join("#" if i in chord else "-" for i in range(4))
    thumb = "#" if 4 in chord else "-"
    return thumb + " " + fingers

# ─── content: stages walked by Guided + Hint, words used by Timed ────
# Letters grouped by chord size (= difficulty = ~frequency, since the alpha
# map is frequency-ordered), then numbers.
_STAGES = [
    ("L1", "EIAS"),       # single finger
    ("L2", "ROCNLT"),     # two fingers
    ("L3", "DPU"),        # three / four fingers
    ("L4", "MGHB"),       # thumb + one
    ("L5", "YWXFKVJZQ"),  # thumb + more
    ("N1", "1234"),       # single-finger numbers
    ("N2", "567890"),     # number combos
]

# Timed mode types whole phrases (Monkeytype-style): several short common
# words + spaces, for realistic speed practice. Lowercase, letters + spaces
# only; each wraps to <=3 rows of 10 chars.
_PHRASES = [
    "the cat ran to the sun",
    "we sit in the red car",
    "a dog and a cat play",
    "she had a cup of tea",
    "run to the top of it",
    "he put the box on it",
    "let us go for a walk",
    "i can see the big sun",
    "the man sat on a log",
    "we go up the big hill",
    "the sea is far from us",
    "a red bus is on the way",
]

# ─── state ───────────────────────────────────────────────────────────
_phase = "menu"          # "menu" | "play"
_mode = None             # "guided" | "hint" | "timed"

_GAME_MENU = ["Guided", "Hint Miss", "Timed", "Back"]
_menu_idx = 0

# guided / hint
_stage_idx = 0
_queue = []              # remaining (char, chord) for the current stage
_cleared = 0             # chars cleared in this stage
_stage_total = 0
_miss = False            # last attempt was wrong (reveal pattern in hint mode)

# timed (phrase typing)
_W = 10                  # display columns (mirrors code.py COLS) for wrapping
_phrase_idx = 0
_cpos = 0                # index of the next char to type in the phrase
_t0 = 0.0
_last_time = 0.0
_last_wpm = 0
_errors = 0

def _now():
    return time.monotonic()

# ─── public entry points ─────────────────────────────────────────────
def start():
    """Enter the game; show the mode picker."""
    global _phase, _menu_idx
    _phase = "menu"
    _menu_idx = 0
    return _menu_lines()

def handle(use):
    """Process one released chord. Returns display lines, or 'EXIT'."""
    if _phase == "menu":
        return _handle_menu(use)
    if _mode == "timed":
        return _handle_timed(use)
    return _handle_drill(use)   # guided + hint

# ─── mode picker ─────────────────────────────────────────────────────
def _menu_lines():
    lines = []
    for i, name in enumerate(_GAME_MENU):
        lines.append(((">" if i == _menu_idx else " ") + name)[:10])
    return lines

def _handle_menu(use):
    global _menu_idx, _phase, _mode
    n = len(_GAME_MENU)
    if use == (0,):
        _menu_idx = (_menu_idx - 1) % n
        return _menu_lines()
    if use == (3,):
        _menu_idx = (_menu_idx + 1) % n
        return _menu_lines()
    if use in ((1,), (2,), (1, 2)):
        choice = _GAME_MENU[_menu_idx]
        if choice == "Back":
            return "EXIT"
        if choice == "Guided":
            return _start_drill("guided")
        if choice == "Hint Miss":
            return _start_drill("hint")
        if choice == "Timed":
            return _start_timed()
    return _menu_lines()

# ─── guided / hint drill ─────────────────────────────────────────────
def _load_stage():
    global _queue, _cleared, _stage_total, _miss
    _name, chars = _STAGES[_stage_idx]
    _queue = [(c, _chord_for(c)) for c in chars if _chord_for(c)]
    _cleared = 0
    _stage_total = len(_queue)
    _miss = False

def _start_drill(mode):
    global _phase, _mode, _stage_idx
    _phase = "play"
    _mode = mode
    _stage_idx = 0
    _load_stage()
    return _drill_lines()

def _drill_lines():
    name = _STAGES[_stage_idx][0]
    if not _queue:
        return ["", "  done!", "%s clear" % name, "", ""]
    ch, chord = _queue[0]
    head = "%s  %d/%d" % (name, _cleared, _stage_total)
    show_pattern = (_mode == "guided") or _miss
    pat = _pattern(chord) if show_pattern else ""
    if _mode == "guided":
        foot = "copy it"
    else:
        foot = "miss-try" if _miss else "recall"
    return [head, "", "  " + ch, pat, foot]

def _handle_drill(use):
    global _stage_idx, _cleared, _miss
    if not _queue:
        return _drill_lines()
    ch, chord = _queue[0]
    if use == chord:
        _queue.pop(0)
        _cleared += 1
        _miss = False
        if not _queue:
            # stage complete → advance, or finish the whole game
            if _stage_idx + 1 < len(_STAGES):
                _stage_idx += 1
                _load_stage()
                name = _STAGES[_stage_idx][0]
                return ["stage up!", "", "  next:", "  " + name, ""]
            return ["", " ALL DONE", " well done", "", "Back=menu"]
        return _drill_lines()
    _miss = True
    return _drill_lines()
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

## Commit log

2025-09-03 got some pcb and tft going
    [flatchord-B_Cu.dxf, flatchord-B_Mask.dxf, flatchord-B_Paste.dxf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]
2025-09-03 got a board
    ready to burn
    [grippy.kicad_pcb, grippy.kicad_sch]
2025-09-04 milled, stencil
    [grippy-B_Cu.dxf, grippy-B_Mask.dxf, grippy-B_Paste.dxf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]
2025-09-06 got a fairly usable case
    [flatchord-B_Cu.dxf, flatchord-B_Mask.dxf, flatchord-B_Paste.dxf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]
2025-09-06 case looks tight
    really slammed the key inserts right up against the mechanical buttons
    [grippy.FCStd]
2025-09-08 display running + chords
    quickly changed over to ST7789 got chords going. adding addition lines for more chars.
    [grippy.FCStd]
2025-09-12 bumped the size up
    [grippy-Edge_Cuts.dxf, grippy-F_Cu.dxf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]
2025-09-12 height adjustment on case
    [grippy.FCStd]
2025-09-12 new stl
    [grippy-cap001.stl, grippy.FCStd]
2025-09-14 design changes
    having a working unit, still needs refinemine for speed
    [grippy-button_fingers.stl, grippy-button_thumb.stl, grippy-cap001.stl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]
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2025-09-14 tighten up fixed vars
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2025-09-24 new design
    shorter, thicker with big fat pink buttons. plenty of room for a 150mA battery.
    [grippy-B_Cu.dxf, grippy-B_Mask.dxf, grippy-B_Paste.dxf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]
2025-09-25 fabbed / printed
    untested, but the physical fit and layout look good.
    [grippy-B_Cu.dxf, grippy-B_Mask.dxf, grippy-B_Paste.dxf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]
2025-09-27 kicad mods
    * raised display height to 8mm
    * slide thumb button
    * changed tft header location 1.25mm slide toward mcu
    * rotated power plug
    [grippy-B_Mask.dxf, grippy-F_Cu.dxf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]
2025-10-01 working model
    [grippy-B_Mask.dxf, grippy-Edge_Cuts.dxf, grippy-F_Cu.dxf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]
2025-10-01 cap pwrswitch cutout, thumb holder, .6 mechchanical switch size
    [grippy-cap.stl, grippy.FCStd]
2025-10-01 changed mechanical button gap to 0.8mm, ideal
    [grippy-button_fingers.stl, grippy-button_thumb.stl, grippy.FCStd]
2025-10-10 display wait for come up
    every other power on was preventing the display from coming up.
2025-10-18 added new rt angle display connector
    [grippy-B_Cu.dxf, grippy-B_Mask.dxf, grippy-B_Paste.dxf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]
2025-10-19 new rt ang pcb stable started case
    [grippy-B_Cu.dxf, grippy-B_Mask.dxf, grippy-B_Paste.dxf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]
2025-10-20 finished adaptation to rt ang
    now buttons will fit on rt angle dropped display which has a 5mm gap / standoffs
    [grippy-base.step, grippy-base.stl, grippy-button_fingers.step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]
2025-11-16 repo cleanup / readme started / images
    [grippy-base.3mf, grippy-button_fingers.3mf, grippy-button_thumb.3mf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]
2025-11-17 minor changes
    [grippy.kicad_pcb]
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2025-12-02 added countersinks to top screws
    [grippy-cap.3mf, grippy.FCStd]
2025-12-03 general updates
    ready to cut another pcb
    [grippy.FCStd, grippy.kicad_pcb, grippy.step]
2025-12-17 cut-out for new supermini
    [grippy.kicad_pcb, grippy.step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]
2026-02-04 moved battery receptacle
    [grippy.kicad_pcb]
2026-02-04 thumb support
    [grippy-cap.3mf, grippy-capPocket049.3mf, grippy.FCStd]
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2026-05-26 update KiCad/FreeCAD design files, add .gitignore
    Add .gitignore to exclude .DS_Store, .FCBak, and backup ZIPs.
    Update PCB, STEP, Gerber, and FreeCAD source files to latest local state.
    [grippy.FCStd, grippy.kicad_pcb, grippy.step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]
2026-05-26 display with full heaers
    [grippy.FCStd, grippy.kicad_pcb]
2026-06-20 Update CAD design files
    [grippy-base.3mf, grippy-button_fingers.3mf, grippy-button_thumb.3mf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]
2026-06-20 working backlight off
    Layer-3 (3,4) thumb+pinky toggles the IO13 backlight off (~80mA saved,
    measured 150mA -> 70mA). Any key on any layer wakes it back on (rising-edge
    gated so the sleep chord's release flicker doesn't re-wake; the wake press
    is consumed). Backlight stays plain on/off (PWM has no effect on this panel).
    [code.py]
2026-06-21 BLE pivot: boot-dark + wake, (3,4) toggles BLE workflow; add resume.md
    WiFi removed (browns out the 130mAh cell at boot). Backlight boots dark and
    any key wakes it. Layer-3 (3,4) toggles supervisor.runtime.ble_workflow for
    wireless notes.txt editing (code.circuitpython.org over BLE from a Mac; Bluefy
    on iOS). resume.md captures full session context for picking up elsewhere.
2026-06-21 fixed WiFi / Screen Blank hot key
    Layer-3 (3,4) chord now toggles WiFi-sync remote mode instead of a plain
    backlight toggle: screen off first, then bring WiFi up (clean radio cycle,
    tx_power=11, retry) and serve notes.txt at grippy.local via adafruit_httpserver.
    Any key wakes: stop server, WiFi radio off, screen back on. Main loop polls
    the server only while remote mode is active. WiFi never comes up at boot, so
    no association brownout; ~130-140 mA screen-off on the 130 mAh cell.
    [code.py]
2026-06-21 Trim to 5 layers + add menu home
    Layers are now: 1 menu, 2 alpha, 3 numeric, 4 space_delim, 5 scag.
    Mouse/media/function layers archived to chords_unused.py.
    Thumb gesture reworked:
    - short tap(s) select the typing layer (1=alpha .. 4=scag)
    - long-hold (>=0.70s) jumps to the menu
    Switching layers never saves; the in-progress note persists so you can
    hop alpha<->numeric (e.g. for a phone number) freely.
    Menu (scrolling, 0=up/3=down, 1/2/(1,2)=select):
    - Save Note (shown only while a note is pending) -> append to notes.txt
    - Add Note (resume/continue buffer)
    - View Note (0/3 prev/next entry)
    - WiFi Sync (screen off + grippy.local server)
    - Clr Note (per-entry delete picker)
    - Clr All (2-step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
    [chords_config.py, chords_unused.py, code.py]
2026-06-21 Auto-save note on long-hold; numeric backspace/space
    - Long-hold to the menu now auto-saves the in-progress note (the only path
    home, so layer switches still never commit). Dropped the Save Note item;
    renamed Add Note -> New Note (always starts fresh).
    - Numeric layer gains the alpha backspace (0,1,3) and space (0,2,3) chords.
2026-06-22 Extract WiFi sync into webserver.py module
    Move the ~125-line WiFi/HTTP block out of code.py into a self-contained
    webserver.py (start/stop/poll/active). The module owns no display or
    backlight; the screen-off-before-association brownout ordering stays in
    code.py's start_remote/stop_remote wrappers, which now just bracket the
    backlight around webserver.start()/.stop(). start() returns False on
    failure so the caller restores the screen.
    [code.py, webserver.py]
2026-06-22 Extract note storage into notes.py; cut dead code
    Move file I/O out of code.py into notes.py (ensure_writable, read_entries,
    append_entry, write_entries). The module owns the ,\n on-disk format and the
    read-only remount dance; code.py keeps thin wrappers managing text_buffer/
    entries and re-rendering. delete_entry now restores the in-memory list if the
    write fails (read-only) instead of desyncing memory from disk.
    Also remove dead code: _insert_code/INSERT_CODE, _kc + KC_* constants, the
    unused handle_page_nav / handle_intra_scroll within-entry-scroll scaffolding,
    and the orphaned WINDOW_SIZE/SAVE_PATH. Drops the storage import from code.py.
    code.py 810 -> 694 lines.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
    [code.py, notes.py]
2026-06-22 Add chord-trainer game (game.py) reachable from the menu
    New "Game" menu item opens a mode picker (Guided / Hint Miss / Timed / Back).
    game.py is logic-only and display-free like notes.py/webserver.py: it returns
    display lines (or "EXIT") and code.py owns the game_mode flag + a _draw_lines
    bridge. Long-hold is the universal exit to the main menu.
    Modes:
    - Guided show target char + finger pattern (#--- -), copy it
    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
2026-06-22 Fix game mode exiting on thumb chords and thumb taps
    Two related issues let the chord trainer drop back to the main menu while
    playing:
    1. Releasing a thumb chord (M=(0,4), B=(3,4), ...) finger-first produced a
    transient lone (4,) that the thumb-gesture detector mistook for a fresh
    thumb press, swallowing the chord and reading the thumb release as a
    tap/long-hold. Fixed with a `thumb_gesture` flag that arms only on a clean
    rising edge from rest and disarms the moment any non-thumb finger joins, so
    a (4,) that is just a chord tail falls through to the game/typing handler.
    2. The numeric stages tempt a double thumb-tap (the normal "switch to numeric
    layer" gesture), which e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
    [code.py]
2026-06-22 Put thumb on the left in the game's finger-pattern display
    _pattern now renders `thumb + space + fingers` (e.g. M=(0,4) -> '# #---')
    instead of fingers-then-thumb, matching the physical orientation of the
    thumb key.
2026-06-22 Make Timed mode type multi-word phrases (Monkeytype-style)
    Replace single 3-4 letter words with 12 six-word phrases typed with spaces,
    for realistic speed practice. You type each letter's chord plus the space
    chord (0,2,3) between words.
    Display (10x5): header shows phrase #/total + live timer; the phrase is
    word-wrapped across 3 rows with typed chars uppercased (the case edge is the
    caret); footer shows the next char (_ = space), and on completion the speed
    as "NNwpm".
    [game.py]
2026-06-23 Add BLE HID keyboard mode (shelved on CP 10.2.x — firmware OOM)
    New ble_hid.py module (mechanism-only, like webserver.py): owns the BLE
    radio, HID-over-GATT services, advertising, and the Keyboard. code.py adds a
    "BLE" menu item that toggles BLE output (mutually exclusive with USB-HID via a
    shared _kbd() router), keeps the radio enabled-but-quiet at boot so the CP BLE
    workflow can't auto-advertise/auto-connect, and shows live Adv/Con status plus
    any enable error on screen.
    Also: menu reorder (New Note, View Note, WiFi Sync, Clr Note, Game Mode, BLE,
    HID, Clr All) and "Game" -> "Game Mode" rename.
    KNOWN LIMITATION: on CircuitPython 10.2.x / ESP32-S3, enabling BLE fails with
    "Unknown syste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
    [ble_hid.py, code.py]
2026-06-23 Make BLE HID work on CircuitPython 10.3.x (finite advertising timeout)
    10.3.0-alpha.2 cleared the 10.2.x error-519 controller-OOM (via upstream PR
    #11036), but exposed a second issue: on NimBLE 6.0.1 the "advertise forever"
    default (timeout None/0) is rejected with "Invalid BLE parameter", and the
    advertising duration is capped (~60-80s; 60 works, 90 fails).
    Fix: advertise in finite 60s windows (_ADV_TIMEOUT) re-armed by poll(), which
    is now rate-limited (>=3s between attempts) so it can't hammer start_advertising
    during the connect window. Verified end-to-end on 10.3.0-alpha.2: pairs as a
    keyboard on macOS and types over BLE.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
    [ble_hid.py]
2026-06-23 Turn off the onboard NeoPixel at boot (power + covered by case)
    CircuitPython drives the WS2812 on board.NEOPIXEL as a status LED. Drive it to
    black via the built-in neopixel_write (no neopixel lib) and release the pin so
    it stays dark while code.py runs. (The red power LED is hardwired to 3V3 and is
    not software-controllable.)
2026-06-23 Add "Clr BLE" menu item to erase BLE bonds on-device
    Pairing fails after the first successful pair when the on-device bond and
    the host bond drift apart (the macOS "stuck on pairing" / connects-without-
    typing symptom). Recovery needed _bleio.adapter.erase_bonding() over the
    REPL because erase_pairing() in ble_hid.py was never wired up.
    Add a "Clr BLE" menu item (between BLE and HID) that calls
    ble_hid.erase_pairing(), with the same two-tap confirm as "Clr All" so it
    can't be triggered by accident. Full stale-bond recovery is now Clr BLE on
    the device + Forget This Device on the host, then re-pair -- no REPL.
    Also deploys the rewritten ble_hid.py (build-once GATT, finite advertise
    window,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
    [ble_hid.py, code.py]
2026-06-24 Disable BLE workflow + disconnect on BLE-off
    Root-caused the BLE flakiness to CircuitPython's built-in BLE WORKFLOW
    running alongside ble_hid.py on the single radio. The workflow advertised as
    CIRCUITPYxxxx and re-advertised after every disconnect, which caused:
    * the stray "CIRCUITPYac58e" name during scan,
    * the host (macOS) staying connected after BLE was turned off (the workflow
    re-advertised, so macOS reconnected),
    * flaky / "spinning" pairing (two advertisers competing for one adapter).
    Fixes:
    * boot.py: supervisor.runtime.ble_workflow = False before the workflow
    starts (the only reliable place, on a hard reset).
    * code.py: same line in the boot block to cover soft r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
    [ble_hid.py, boot.py, code.py]
2026-06-25 Serve notes.txt from a raw socket, not adafruit_httpserver
    WiFi Sync got an IP on-device but answered ping/HTTP slowly or not at
    all on a fresh power-on. Root cause was heap, not radio/creds/menu:
    adafruit_httpserver costs ~25 KB to import, and loading it at sync time
    on top of the display + app left only ~12 KB free — too little for the
    lwIP stack to allocate packet buffers. From the REPL (71 KB free) the
    same start() worked, which is why it looked like an on-device-path bug.
    Replace it with a ~20-line raw socketpool HTTP responder that serves the
    single static notes.txt file. socketpool/mdns/wifi are firmware built-ins
    (~0 Python heap), so ~25 KB more stays free: measured ~133 KB free a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
    [webserver.py]
2026-06-25 Fix WiFi Sync failing after first attempt: deinit mDNS in stop()
    mdns.Server can only be created once per boot, but stop() only nulled the
    Python reference and never freed the firmware mDNS instance. So the 2nd
    and later WiFi Sync attempts in a boot threw "mDNS already initialized"
    and start() aborted — the menu path appeared to "work once then break,"
    which matches the long-standing "WiFi Sync fails from the menu" symptom.
    - stop() now calls _mdns.deinit() before dropping the reference, so the
    next start() can recreate it. Verified: 3 back-to-back start/stop cycles
    all succeed (previously #2 failed).
    - start() now treats mDNS as best-effort: if mdns.Server() ever throws
    (e.g. a lea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
    [webserver.py]
2026-06-25 BLE off at boot, enable on demand; commit settings.toml stub
    BLE radio (~current at every boot even when unused):
    - code.py no longer enables _bleio.adapter at boot; it sets it OFF and only
    ble_hid.start() powers it up the first time the BLE menu item is used.
    - ble_hid.start() calls a new _enable_adapter() (idempotent, 0.2 s settle) so
    the adapter.enabled toggle still happens once, with _build() between it and
    start_advertising — preserving the "never toggle enabled next to advertising"
    rule that avoided controller corruption. Left on for the rest of the session
    so the build-once GATT still holds. erase_pairing() also powers it up first.
    - Verified on stock 10.3.0-alpha.3: off a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
    [ble_hid.py, code.py]
2026-06-25 Idle the CPU while the screen is off (WiFi Sync / sleep power fix)
    The main loop ran at SCAN_LOOP=0.001 (≈1000 Hz) unconditionally, so the
    ESP32-S3 CPU never idled even with the screen off. During WiFi Sync this
    doubled the screen-off draw — measured on a USB power meter at 140 mA
    busy-spin vs 70 mA when the CPU is allowed to idle (same WiFi connection,
    same backlight-off). WiFi power-save (power_management=MIN) was working the
    whole time; the radio was never the cause.
    Fix: add SLEEP_LOOP=0.05 and sleep SCAN_LOOP only while bl.value is True
    (screen on / typing). With the screen off there is nothing to type, so 20 Hz
    is plenty to wake on a keypress and to poll the HTTP server, and it le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
    [code.py]
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
